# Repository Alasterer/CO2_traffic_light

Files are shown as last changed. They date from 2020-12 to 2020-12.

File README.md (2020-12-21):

# CO2 Traffic Light
DIY CO2 sensor with traffic light and 7-segment display for air quality indication.

<p float="left">
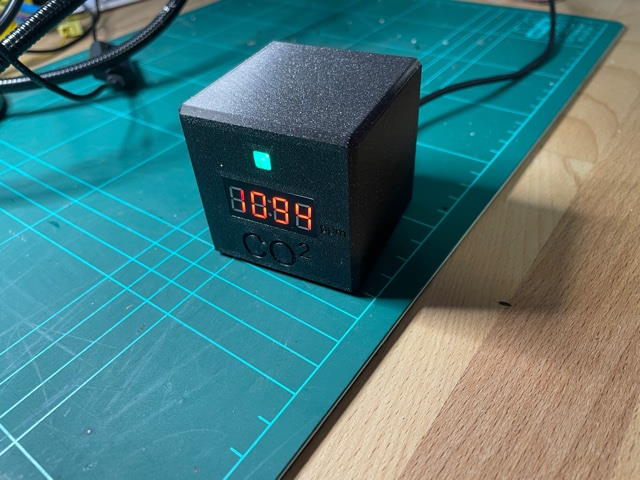
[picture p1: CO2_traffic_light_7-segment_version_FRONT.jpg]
 
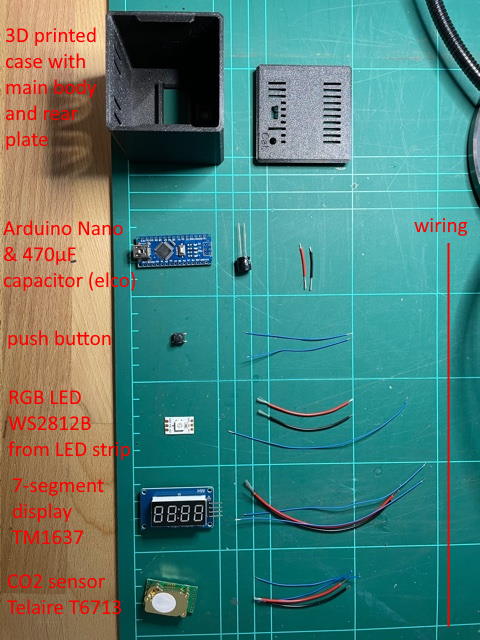
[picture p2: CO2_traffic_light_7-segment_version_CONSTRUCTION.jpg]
 
</p>
<p float="left">
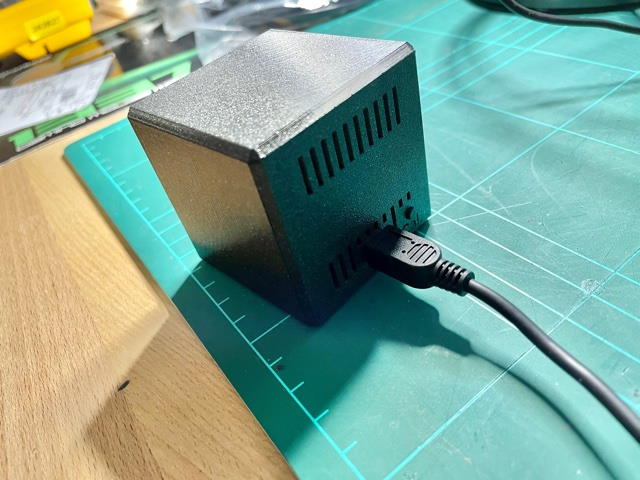
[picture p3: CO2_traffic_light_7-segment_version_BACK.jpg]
 
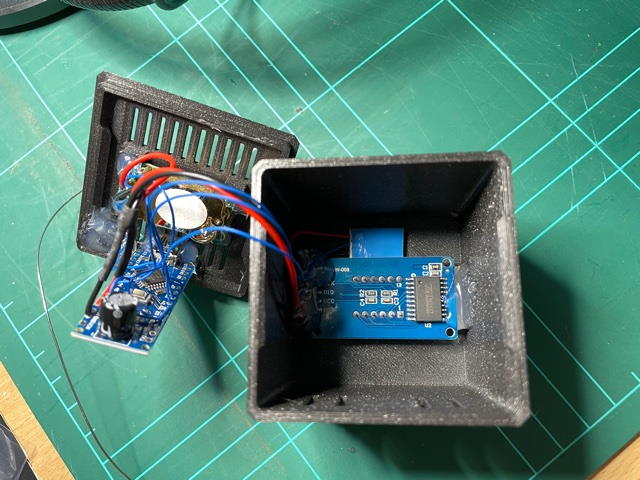
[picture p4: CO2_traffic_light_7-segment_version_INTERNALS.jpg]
 
</p>

## Purpose

I wanted to be able to measure the CO2 content of the air inside my appartment and the office.
The targets are:
  * To preventing the spread of the corona virus (adhering to the guidelines) I need to be able to know when the room needs fresh air (especially useful when colleagues are in the same office space)
  * Prevent high CO2 content in the room since this impacts directly my productivity and ability to think straight (especially useful during work hours)

## 7-segment version

DIY CO2 sensor with the following features:
  * CO2 sensor ([Telaire T6713](https://www.14core.com/wiring-the-telaire-t6713-t67xx-a-carbon-dioxide-co2-sensor/amp), [PDF datasheet](https://www.mouser.com/pdfDocs/AAS-916-142A-Telaire-T67xx-CO2-Sensor-022719-web.pdf)) for measuring real air CO2 content (it is not a equivalent CO2 sensor)
  * 7-segment display ([TM1637](https://www.makerguides.com/tm1637-arduino-tutorial), 4 digits, [PDF datasheet controller](https://www.mcielectronics.cl/website_MCI/static/documents/Datasheet_TM1637.pdf)) to show current CO2 measurement in ppm (unit for CO2)
  * RGB LED ([WS2812B](https://www.mschoeffler.de/2017/08/24/how-to-control-an-led-pixel-strip-ws2812b-with-an-arduino-and-the-fastled-library), [PDF datasheet](https://cdn-shop.adafruit.com/datasheets/WS2812B.pdf)) as traffic light to show the current air quality assessment. The following values are averaged over multiple online sources regarding CO2 threshold levels and were experimentally tested to be good values (air feels "stuffy" vs. air feels "clean"):
    * 0 to 1600 ppm: green light, air quality is good
    * 1600 to 2200 ppm: yellow light, air quality could be better, please air the room
    * above 2200 ppm (max for sensor is 5000 ppm): red light, air quality is bad, concentration problems could occur above this threshold, air room as soon as possible
  * Push button with 2 functions:
    * short press (< 1 s): change brightness of RGB LED and 7-segment display. Useful to adjust brightness for use at night or with direct sunlight.
    * long press (>= 10 s): start and perform calibration of CO2 sensor (Telaire T6713). Calibration takes about 7 to 8 minutes to complete.
  * Central microcontroller module (Arduino Nano, [Pinout](https://i.pinimg.com/originals/c4/87/21/c487213e9081fb0050878a02304e5693.png), [PDF datasheet microcontroller ATMega328P](http://ww1.microchip.com/downloads/en/DeviceDoc/Atmel-7810-Automotive-Microcontrollers-ATmega328P_Datasheet.pdf)) outputs new CO2 ppm value as simulated serial port with 115200 baud. You can use general tools for accessing the serial data or use my Python scripts:
    * [serial_logger_v5_working.py](https://github.com/Alasterer/CO2_traffic_light_7_segment/blob/main/serial_logger_v5_working.py): Logging serial data
      * Records to .csv files
      * Names .csv files after current date and time
      * Creates counter at end of file name if file with same name is present
      * Starts new .csv file after midnight to keep data steam manageable
      * Creates time stamps in front of measurement data and records this to .csv files as the first element in each line
    * [plot_serial_data_v2_working.py](https://github.com/Alasterer/CO2_traffic_light_7_segment/blob/main/plot_serial_data_v2_working.py): Plot measurement data to live graph with .png export

### Notes
  * There is a small window in front of the RGB LED which was printed using clear PLA (noname brand material)
  * The main body and rear plate were printed using [PLA Prusament Galaxy Black](https://shop.prusa3d.com/de/prusament/711-prusament-pla-prusa-galaxy-black-1kg.html) which prints very nicely. Layer height was 0.2mm using a Prusa i3 MK3S with standard prusament settings set in Prusa Slicer.

### Block diagram
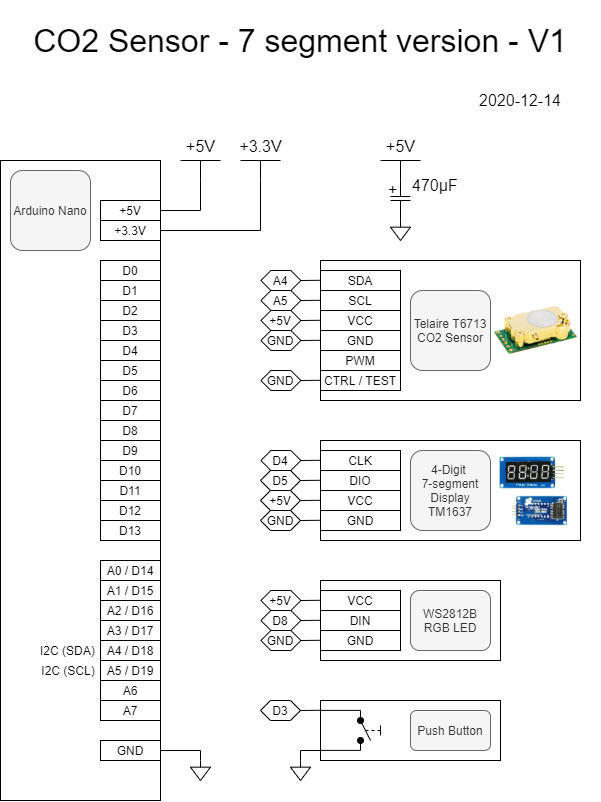
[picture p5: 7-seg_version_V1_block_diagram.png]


---

## LCD display version

It is planned to complete a version with LCD display (Nokia 5110) that has several more features:
  * [Nokia 5110 LCD display](https://learn.sparkfun.com/tutorials/graphic-lcd-hookup-guide) (has background LED), [PDF datasheet controller](https://www.sparkfun.com/datasheets/LCD/Monochrome/Nokia5110.pdf)
  * Push buttons, 3x, SMD: For navigating on screen menu on LCD screen
  * Night light LED (warm white, 5V, PWM dimming) for soft room illumination at night
  * Photoresistor ([GL5516](http://static.cactus.io/img/sensors/light/ldr/ldr-circuit.jpg) with 5 to 10 kOhm at 10 Lux) for detection ambient light levels (can be used to dim RGB LED, Night light LED and/or display backlight)
  * Connector for [BMP180 sensor module](http://www.esp8266learning.com/wemos-mini-bmp180-shield.php), [PDF datasheet](https://cdn-shop.adafruit.com/datasheets/BST-BMP180-DS000-09.pdf): Can measure temperature and ambient barometric pressure. Values will be display on LCD as well
  * Connector for [NRF24L01 communication module](https://lastminuteengineers.com/nrf24l01-arduino-wireless-communication/), [PDF datasheet](https://www.sparkfun.com/datasheets/Components/SMD/nRF24L01Pluss_Preliminary_Product_Specification_v1_0.pdf):
    * Use case 1: Communicate with separate Arduino that activates fan to vent room when CO2 levels are too high
    * Use case 2: Communicate with Raspberry Pi for recording measurement values

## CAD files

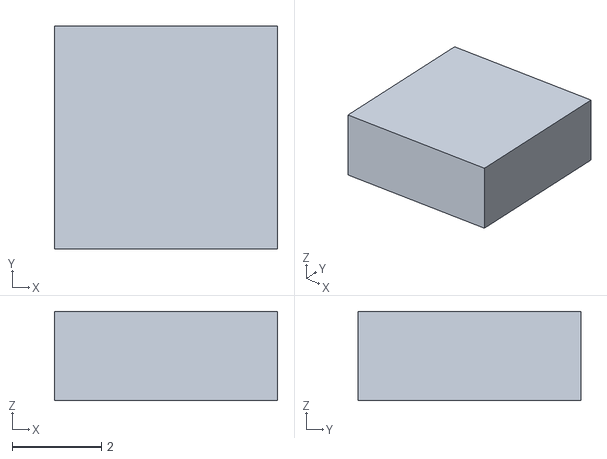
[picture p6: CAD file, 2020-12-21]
CO2 Ampel Version 7-Segment Tischgeraet v31 - Clear window.stl
5.00 x 5.00 x 2.00

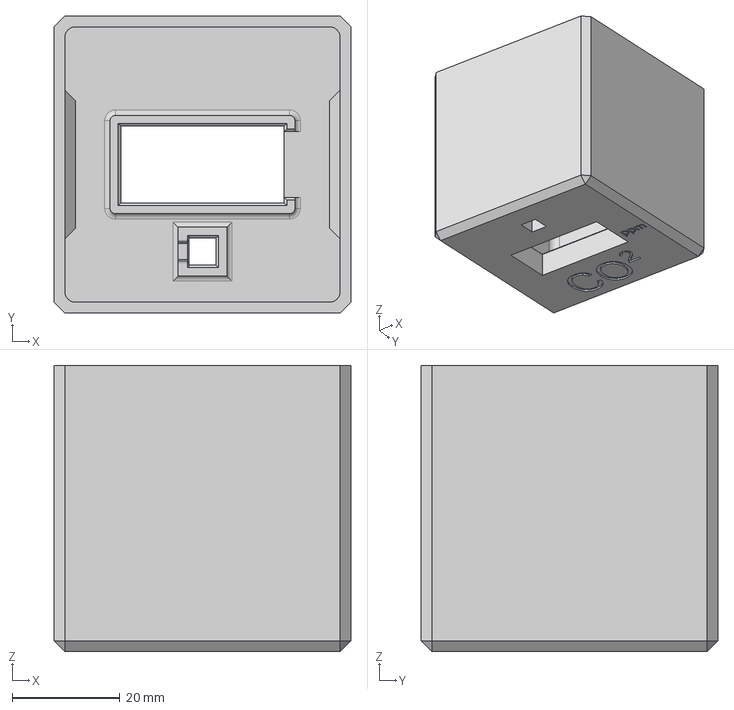
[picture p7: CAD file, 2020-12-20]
CO2 Ampel Version 7-Segment Tischgeraet v31.step
55.0 x 55.0 x 53.0 mm

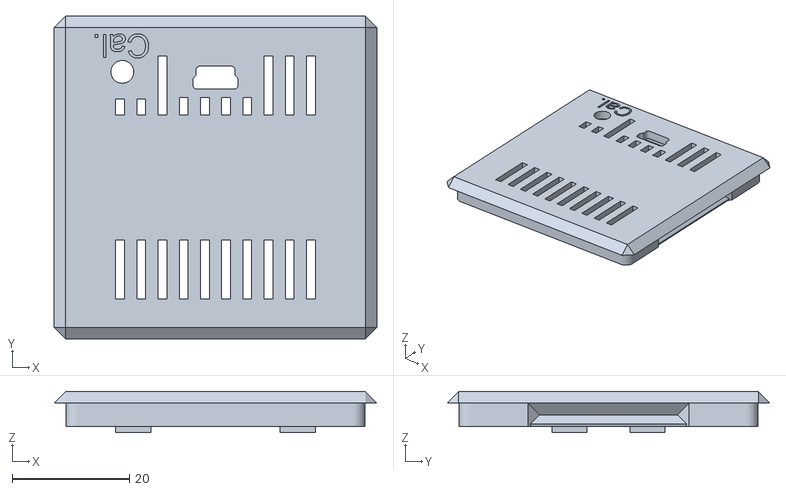
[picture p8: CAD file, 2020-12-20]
CO2 Ampel Version 7-Segment Tischgeraet v31 - Deckel.stl
55.0 x 55.0 x 7.00

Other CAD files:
CO2 Ampel Version 7-Segment Tischgeraet v31 - Hauptkoerper.stl

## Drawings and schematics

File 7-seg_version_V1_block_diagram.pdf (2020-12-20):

+5V +3.3V

# CO2 Sensor - 7 segment version - V1

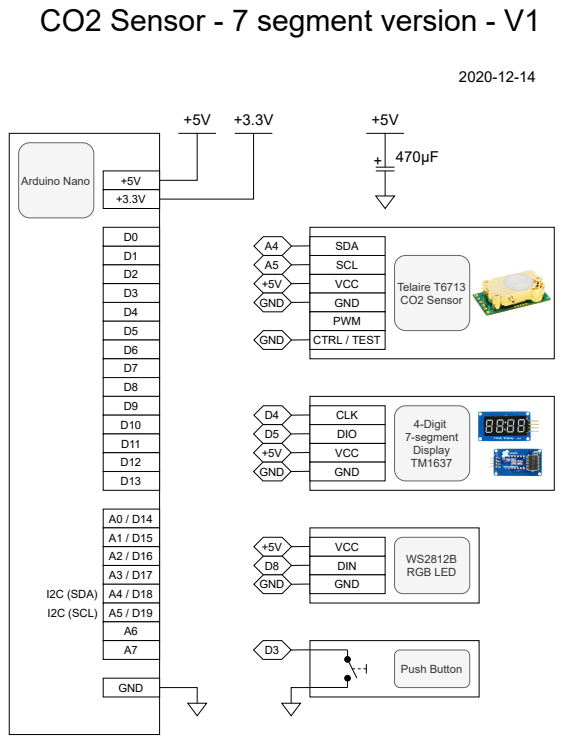
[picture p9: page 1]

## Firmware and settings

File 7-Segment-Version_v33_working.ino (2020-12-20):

#include <Arduino.h>
#include <TM1637Display.h>  // include for 7-segment display TM1637
#include <Wire.h>           // include for CO2 Sensor Telaire T67xx (i have T6713)
#include <FastLED.h>        // inclue for RGB LED WS2812B
//#include <EEPROM.h>         // for saving variables

// ----- Define Pins ----------------------------------

// 7 segment display pins
#define CLK       (byte)4
#define DIO       (byte)5

// push button pins
#define buttonpin (byte)3

// RGB LED WS2812B pins
#define RGBLEDpin (byte)8

// ----- Define parameters ----------------------------
//#define SeuilPPM1 (int)900        //1er Seuil d'alerte au CO2 (900 PPM : air bon à moyen)
#define Level_yellow (int)1600       //2nd Seuil d'alerte au CO2 (1600 PPM : air moyen à mauvais, ventillation conseillee)
#define Level_red (int)2200       //3e Seuil d'alerte au CO2 (2200 PPM : mauvais air, maux de tetes, malaise possible, ventillation indispensable)
#define T6713_Address 0x15 //T6713 i2C Address

int SensorInterval = 5500;   // Interval for reading CO2 sensor values

byte co2_offset;


unsigned long loadTime = 2000;     //temps de "chauffe" du capteur CO2
unsigned long calibrationTime = 420000;   // 7 * 60000;   // calibration take 6 min so we set 7 min to be sure that calibration is finished
int loadSpeed = 10;       //rapiditée de l'animation de chargement
int messageInterval = 4;  //fréquence des messages d'alerte si un seuil CO2 est passé (4 par défaut)
bool button_state;

uint8_t CO2[] = { 0x39, 0x5c, 0x5b, 0x00 };   // code for showing "CO2"  on 7-segment display
uint8_t CAL[] = { 0x39, 0x77, 0x38, 0x00 };   // code for showing "CAL"  on 7-segment display
uint8_t Done_Display[] = { 0x5E, 0x5c, 0x54, 0x79 };  // code for showing "DONE" on 7-segment display

// init variables and objects   
TM1637Display displayScreen(CLK, DIO);
unsigned long getDataTimer = 20000;
int CO2PPM = 0;
int messageBox = 0;

CRGB leds[1];     // Define variables for RGB LED WS2812B
byte led_state = 0;             //0=off, 1=green, 2=yellow, 3=red, 4=blue, 5=pink
byte previous_led_state = 0;    //0=off, 1=green, 2=yellow, 3=red, 4=blue, 5=pink
//byte overall_brightness;    //1=lowest , 2=normal , 3=high , 4=very high brightness
int overall_brightness = 1;    //1=lowest , 2=normal , 3=high , 4=very high brightness
float brightness = 2.0;
byte brightness_RGB_LED = 15;



// ----- Setup ---------------------------------------//

void setup()
{
  // init and set input and output pins
  pinMode(buttonpin, INPUT_PULLUP);
  pinMode(RGBLEDpin, OUTPUT);
  digitalWrite(RGBLEDpin, LOW);     // init RGB LED data channel with LOW

  // init and start serial
  Serial.begin(115200);

  // start I2C communication
  Wire.begin();  

  // init and start EEPROM library
  //EEPROM.begin(4);        // start reading EEPROM and use only first 4 bytes or EEPROM memory (4096 byte would be possible)

  // Start RGB LED
  FastLED.addLeds<WS2812B, RGBLEDpin, RGB>(leds, 1);
  clearLED();

  // initialize and set 7-seg display and RGB LED brightnesses
  //init_brightness();
  set_brightness();             // increases overall_brightness to 2 and sets the "normal" setting

  // set 7-seg display
  uint8_t clear_lcd_data[] = {0x40, 0x40, 0x40, 0x40};
  displayScreen.setSegments(clear_lcd_data);                  // writes only dashes to 7-segment display

  //readSensor();
  //loadingAnimation();                                         // Start loading animation

  // Start CO2 sensor
  turnonABCLogic();

  // print welcome message
  //Serial.println(F("Sensor stared and active!"));
}

// ----- MAIN PROGRAM ---------------------------------------//

void loop() {
  button_state = digitalRead(buttonpin);
  if ( button_state == 0 ){
    delay(500);
    button_state = digitalRead(buttonpin);
    if ( button_state == 1 ){
      previous_led_state = led_state; 
      for(int i=0; i<2; i++){
        setLED_pink();
        delay(100);
        clearLED();
        delay(100);        
      }            
      set_brightness();
    } else{
      delay(9500);
//      previous_led_state = led_state;
//      for(int i=0; i<15; i++){
//        setLED_blue();
//        delay(100);
//        clearLED();
//        delay(100);        
//      }
//      led_state = previous_led_state;
      button_state = digitalRead(buttonpin);
      if ( button_state == 0 ){
        displayScreen.setSegments(CAL);
        setLED_blue();
        //delay(7000);      
        loadTime = calibrationTime;
        loadSpeed = 420;       //rapiditée de l'animation de chargement
        calibrateSensor();
        //loadingAnimation();
        //calibrationAnimation();      
        clearLED();
        displayScreen.setSegments(Done_Display);
        getDataTimer = millis();
      }
    }
  }

  if (millis() - getDataTimer >= SensorInterval)
  {
    getDataTimer = millis();
    //CO2PPM = CO2PPM + 200;
    // getStatus_short_output();
    CO2PPM = readSensor() + co2_offset;
    // getStatus_short_output();
    if (CO2PPM > 370) {
      Serial.println(CO2PPM);
      if ( CO2PPM < Level_yellow){
        setLED_green();
      } else if ( CO2PPM >= Level_yellow && CO2PPM < Level_red ){
        setLED_yellow();
      } else {
        setLED_red();
      }
      //displayScreen.showNumberDecEx(CO2PPM, false);
      displayScreen.showNumberDec(CO2PPM);
    }
  }
}


// --------------------------------------------------------//

//void calibrationAnimation() {
//  uint8_t loadA[] = { 0x39, 0x77, 0x38, 0x01 };                //loading animation 1/6
//  uint8_t loadB[] = { 0x39, 0x77, 0x38, 0x02 };                //loading animation 2/6
//  uint8_t loadC[] = { 0x39, 0x77, 0x38, 0x04 };                //loading animation 3/6
//  uint8_t loadD[] = { 0x39, 0x77, 0x38, 0x08 };                //loading animation 4/6
//  uint8_t loadE[] = { 0x39, 0x77, 0x38, 0x10 };                //loading animation 5/6
//  uint8_t loadF[] = { 0x39, 0x77, 0x38, 0x20 };                //loading animation 6/6
//
//  int delay_per_segment = 400;
//  calibrationTime = 4800;
//  int runtime = (int)calibrationTime / (6 * delay_per_segment);
//  for (int i = 0; i <= runtime; i++) {
//    displayScreen.setSegments(loadA);
//    delay(delay_per_segment);
//    displayScreen.setSegments(loadB);
//    delay(delay_per_segment);
//    displayScreen.setSegments(loadC);
//    delay(delay_per_segment);
//    displayScreen.setSegments(loadD);
//    delay(delay_per_segment);
//    displayScreen.setSegments(loadE);
//    delay(delay_per_segment);
//    displayScreen.setSegments(loadF);
//    delay(delay_per_segment);
//  }
//  displayScreen.clear();
//}

void loadingAnimation()
{
  uint8_t loadA[] = { 0x30, 0x00, 0x00, 0x00 };                //animation de chargment 1/5
  uint8_t loadB[] = { 0x06, 0x30, 0x00, 0x00 };                //animation de chargment 2/5
  uint8_t loadC[] = { 0x00, 0x06, 0x30, 0x00 };                //animation de chargment 3/5
  uint8_t loadD[] = { 0x00, 0x00, 0x06, 0x30 };                //animation de chargment 4/5
  uint8_t loadE[] = { 0x00, 0x00, 0x00, 0x06 };                //animation de chargment 5/5

  //Affiche l'aniamtion en boucle
  for (int i = 0; i <= loadSpeed; i++) {
    displayScreen.setSegments(loadA);
    delay((loadTime / loadSpeed) / 5);
    displayScreen.setSegments(loadB);
    delay((loadTime / loadSpeed) / 5);
    displayScreen.setSegments(loadC);
    delay((loadTime / loadSpeed) / 5);
    displayScreen.setSegments(loadD);
    delay((loadTime / loadSpeed) / 5);
    displayScreen.setSegments(loadE);
    delay((loadTime / loadSpeed) / 5);
  }
  //uint8_t clear_lcd_data[] = {0x00, 0x00, 0x00, 0x00};
  uint8_t clear_lcd_data[] = {0x40, 0x40, 0x40, 0x40};
  displayScreen.setSegments(clear_lcd_data);
}

void setLED_red(){
  //leds[0] = CRGB( 255, 0, 0);  // Set RGB LED to green
  leds[0] = CRGB( 0, 255, 0);  // Set RGB LED to red
  //leds[0] = CRGB( 0, 0, 255);  // Set RGB LED to blue
  FastLED.setBrightness(brightness_RGB_LED);  // Set brightness to 5 (0...255 possible)
  FastLED.show();
  led_state = 3;
}

void setLED_yellow(){
  //leds[0] = CRGB( 255, 0, 0);  // Set RGB LED to green
  //leds[0] = CRGB( 0, 255, 0);  // Set RGB LED to red
  //leds[0] = CRGB( 0, 0, 255);  // Set RGB LED to blue
  leds[0] = CRGB( 190, 255, 0);  // Set RGB LED to yellow
  FastLED.setBrightness(brightness_RGB_LED);  // Set brightness to 5 (0...255 possible)
  FastLED.show();
  led_state = 2;
}

void setLED_green(){
  leds[0] = CRGB( 255, 0, 0);  // Set RGB LED to green
  //leds[0] = CRGB( 0, 255, 0);  // Set RGB LED to red
  //leds[0] = CRGB( 0, 0, 255);  // Set RGB LED to blue
  FastLED.setBrightness(brightness_RGB_LED);  // Set brightness to 5 (0...255 possible)
  FastLED.show();
  led_state = 1;  
}

void setLED_blue(){
  //leds[0] = CRGB( 255, 0, 0);  // Set RGB LED to green
  //leds[0] = CRGB( 0, 255, 0);  // Set RGB LED to red
  leds[0] = CRGB( 0, 0, 255);  // Set RGB LED to blue
  FastLED.setBrightness(brightness_RGB_LED);  // Set brightness to 5 (0...255 possible)
  FastLED.show(); 
  led_state = 4; 
}

void setLED_pink(){
  //leds[0] = CRGB( 255, 0, 0);  // Set RGB LED to green
  //leds[0] = CRGB( 0, 255, 0);  // Set RGB LED to red
  //leds[0] = CRGB( 0, 0, 255);  // Set RGB LED to blue
  leds[0] = CRGB( 255, 84, 167);  // Set RGB LED to blue
  FastLED.setBrightness(brightness_RGB_LED);  // Set brightness to 5 (0...255 possible)
  FastLED.show(); 
  led_state = 5; 
}

void clearLED(){
  FastLED.clear();  // clear all pixel data
  FastLED.show();
  led_state = 0;
}

// Read current sensor value of Telaire T6713
int readSensor(){
  // start I2C
  Wire.beginTransmission(T6713_Address);
  Wire.write(0x04); Wire.write(0x13); Wire.write(0x8B); Wire.write(0x00); Wire.write(0x01);
  Wire.endTransmission();
  
  // read report of current gas measurement in ppm
  delay(5);  
  Wire.requestFrom(T6713_Address, 4); //Request 4 bytes from the sensor
  int data [4];  
  data[0] = Wire.read();
  data[1] = Wire.read();
  data[2] = Wire.read();
  data[3] = Wire.read();
//  Serial.print("FUNCTION CODE: ");
//  Serial.println(data[0], HEX);
//  Serial.print("BYTE COUNT: ");
//  Serial.println(data[1], HEX);
//  Serial.print("MOST SIGNIFICANT BIT (HEX): ");
//  Serial.println(data[2],HEX);
//  Serial.print("LEAST SIGNIFICANT BIT (HEX): ");
//  Serial.println(data[3],HEX);
  int ppmValue = ((data[2] & 0x3F ) << 8) | data[3];
  return ppmValue;
}

// Calibrate sensor Telaire T6713
void calibrateSensor(){
  Serial.println(F("Calibrating sensor, please wait..."));
  
  // start I2C and request to start Single Point Calibration (I2C)
  Wire.beginTransmission(T6713_Address);  // T6713_Address = 0x15 by default
  Wire.write(0x05); Wire.write(0x03); Wire.write(0xEC); Wire.write(0xFF); Wire.write(0x00);
  Wire.endTransmission();

  // read Modbus Response (I2C) during calibration to see if calibration has finished
  int counter = 48;   // wait for 8 min to be sure that calibration has finished
  while(counter > 0){
    delay(10000);  
    getStatus_short_output();
    counter = counter - 1;
  }

  Serial.println(F("Calibration: DONE"));
}


// Turn on ABC Logic for sensor Telaire T6713 and read back result
void turnonABCLogic_with_debug_output(){
  // start I2C and request to enable ABC Logic
  turnonABCLogic();
  
  // read Modbus Response (I2C) to command "enable ABC Logic"
  Wire.requestFrom(T6713_Address, 5); //Request 5 bytes from the sensor
  int data [5]; 
  data[0] = Wire.read();
  data[1] = Wire.read();
  data[2] = Wire.read();
  data[3] = Wire.read();
  data[4] = Wire.read();
  Serial.print(F("Turning on ABC logic: FUNCTION CODE: "));
  Serial.print(data[0], HEX);
  Serial.print(F(", Register Address (MSB): "));
  Serial.print(data[1], HEX);
  Serial.print(F(", Register Address (LSB): "));
  Serial.print(data[2],HEX);
  Serial.print(F(", Register Value (MSB) Enable ABC Logic: "));
  Serial.print(data[3],HEX);
  Serial.print(F(", Register Value (LSB) LSB will always be zero: "));
  Serial.println(data[4],HEX);
}


// Turn on ABC Logic for sensor Telaire T6713
void turnonABCLogic(){
  // start I2C and request to enable ABC Logic
  Wire.beginTransmission(T6713_Address);  // T6713_Address = 0x15 by default
  Wire.write(0x05); Wire.write(0x03); Wire.write(0xEE); Wire.write(0xFF); Wire.write(0x00);
  Wire.endTransmission();
  delay(100);
}


//Get firmware version of sensor Telaire T6713
void getFirmwareVersion(){
  // start I2C and request firmware version
  Wire.beginTransmission(T6713_Address);  // T6713_Address = 0x15 by default
  Wire.write(0x04); Wire.write(0x13); Wire.write(0x89); Wire.write(0x00); Wire.write(0x01);
  Wire.endTransmission();
  delay(100);
  
  // read Modbus Response (I2C) to command "enable ABC Logic"
  int data [4];
  Wire.requestFrom(T6713_Address, 4); //Request 4 bytes from the sensor
  data[0] = Wire.read();
  data[1] = Wire.read();
  data[2] = Wire.read();
  data[3] = Wire.read();
  Serial.print(F("Firmware version is (in HEX): 0x"));
  Serial.println(data[2],HEX);
  Serial.println(data[3],HEX);
//  Serial.print(F("FUNCTION CODE (should be HEX 0x04): "));
//  Serial.println(data[0], HEX);
//  Serial.print(F("Byte Count (should be HEX 0x02): "));
//  Serial.println(data[1], HEX);
//  Serial.print(F("Status (MSB): "));
//  Serial.println(data[2],HEX);
//  Serial.print(F("Status (LSB): "));
//  Serial.println(data[3],HEX);
}

// Get current status of sensor Telaire T6713
void getStatus(){
  // start I2C and request firmware version
  Wire.beginTransmission(T6713_Address);  // T6713_Address = 0x15 by default
  Wire.write(0x04); Wire.write(0x13); Wire.write(0x8A); Wire.write(0x00); Wire.write(0x01);
  Wire.endTransmission();
  delay(100);
  
  // read Modbus Response (I2C) to command "enable ABC Logic"
  int data [4];
  Wire.requestFrom(T6713_Address, 4); //Request 4 bytes from the sensor
  data[0] = Wire.read();
  data[1] = Wire.read();
  data[2] = Wire.read();
  data[3] = Wire.read();
  Serial.println(F("RESPONSE: "));
  Serial.print(F("FUNCTION CODE (should be HEX 0x04): "));
  Serial.println(data[0], HEX);
  Serial.print(F("Byte Count (should be HEX 0x02): "));
  Serial.println(data[1], HEX);
  Serial.print(F("Status (MSB): "));
  Serial.println(data[2],HEX);
  Serial.print(F("Status (LSB): "));
  Serial.println(data[3],HEX);
}

// Get current status of sensor Telaire T6713
void getStatus_short_output(){
  // start I2C and request firmware version
  Wire.beginTransmission(T6713_Address);  // T6713_Address = 0x15 by default
  Wire.write(0x04); Wire.write(0x13); Wire.write(0x8A); Wire.write(0x00); Wire.write(0x01);
  Wire.endTransmission();
  delay(100);
  
  // read Modbus Response (I2C) to command "enable ABC Logic"
  int data [4];
  Wire.requestFrom(T6713_Address, 4); //Request 4 bytes from the sensor
  data[0] = Wire.read();
  data[1] = Wire.read();
  data[2] = Wire.read();
  data[3] = Wire.read();
  Serial.print(data[0], HEX);
  Serial.print(F(" / "));
  Serial.print(data[1], HEX);
  Serial.print(F(": "));
  Serial.print(data[2],HEX);
  Serial.println(data[3],HEX);
}

//void init_brightness(){
//  overall_brightness = EEPROM.read(1);
//}

void set_brightness(){
  overall_brightness = overall_brightness + 1;
  if (overall_brightness == 1){
    brightness = 0.1;           //out of 7.0
    brightness_RGB_LED = 1;     //out of 255
  } else if (overall_brightness == 2){
    brightness = 2.0;           //out of 7.0
    brightness_RGB_LED = 15;    //out of 255    
  } else if (overall_brightness == 3){
    brightness = 4.0;           //out of 7.0
    brightness_RGB_LED = 30;    //out of 255     
  } else if (overall_brightness == 4){
    brightness = 7.0;           //out of 7.0
    brightness_RGB_LED = 255;   //out of 255 
  } else {      // overflow case --> reduce overall_brightness to 1
    overall_brightness = 1;
    brightness = 0.1;           //out of 7.0
    brightness_RGB_LED = 1;    //out of 255
  }
  displayScreen.setBrightness(brightness);      // set brightness of 7-segment display
  displayScreen.showNumberDec(CO2PPM);          // show current measurement value
  FastLED.setBrightness(brightness_RGB_LED);    // set brightness of RGB LED
  set_led_to_previous_state();
}

void set_led_to_previous_state(){
  if (previous_led_state == 0){
    clearLED();
  } else if (previous_led_state == 1){
    setLED_green();
  } else if (previous_led_state == 2){
    setLED_yellow();
  } else if (previous_led_state == 3){
    setLED_red();
  } else if (previous_led_state == 4){
    setLED_blue();
  } else if (previous_led_state == 5){
    setLED_pink();
  } else {
    clearLED();
  }
}

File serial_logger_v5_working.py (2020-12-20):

import serial
import time
import csv
import sys
from datetime import datetime
from os import path
import platform

class RelaySerial():
    def __init__(self, comport, debug=False):
        print('Opening communication...')
        self.debug = debug
        self.ser = serial.Serial()
        self.ser.port = comport 
        self.ser.baudrate = 115200
        self.ser.bytesize = serial.EIGHTBITS 
        self.ser.parity = serial.PARITY_NONE
        self.ser.stopbits = serial.STOPBITS_ONE 
        self.ser.xonxoff = False
        self.ser.writeTimeout = 2
        try: 
            self.ser.open()
            read_response = self.ser.readline()   # read a '\n' terminated line --> NEEDED!!! Arduino flash memory can otherwise be overwriten during serial initiation (then needs to be rewritten)
            # print('read_response returned: ', read_response)            
            print('Communication established')
        except Exception:
            print("Class RelaySerial Init: Error open serial port: " + str(comport))
            sys.exit('Class RelaySerial Init: Error open serial port: ' + str(comport)) 
            
    def send(self, commandToSend):            
        if self.ser.isOpen():
            try:
                self.ser.flushInput() 
                self.ser.flushOutput()
                #print("writing to serial: ", commandToSend)
                self.ser.write((commandToSend + '\n').encode())
                # read back the command we just send
                while True:
                    readback_of_send_command = str(self.ser.readline())[3:-1]
                    # print('readback_of_send_command: ', readback_of_send_command)
                    if readback_of_send_command == 'a\\n':
                        print('relay(s) activated with: ', commandToSend)
                        break
                time.sleep(0.5)
                # print('readback_of_send_command: ', readback_of_send_command)
            except Exception:
                print('Error in function send() in class RelaySerial')
                response = None
                
    def read(self):            
        if self.ser.isOpen():
            try:
                self.ser.flushInput() 
                self.ser.flushOutput()
                readback = str(self.ser.readline().decode("utf-8"))
                readback = readback.replace('\r\n','')
                #print(readback)
                time.sleep(0.5)
            except Exception:
                print('Error in function send() in class RelaySerial')
                readback = None
        return readback
                
    def read_loop(self):            
        if self.ser.isOpen():
            try:
                self.ser.flushInput() 
                self.ser.flushOutput()
                # read back the command we just send
                while True:
                    readback = str(self.ser.readline().decode("utf-8"))
                    readback = readback.replace('\r\n','')
                    print(readback)
                    if readback == 'EOF':
                        print('EOF reached')
                        break
                    time.sleep(1)
                time.sleep(0.5)
                # print('readback_of_send_command: ', readback_of_send_command)
            except Exception:
                print('Error in function send() in class RelaySerial')
                response = None                 
                
                
    def closeCom(self):
        """Close communication"""
        print('Closing communication...')
        try:
            self.ser.close()
            if not self.ser.isOpen():
                print('Communication closed successfully')
            else:
                print('Error: Communication could not be closed')
        except:
            print('Error: Communication could not be closed')
            

            
if __name__ == "__main__":
    try:
        delimiter_symbol = ';'
        running_data_file_counter = 1
        
        if platform.system() == 'Windows':
            serial_relay = RelaySerial('COM10', debug=False)
        elif platform.system() == 'Linux':
            serial_relay = RelaySerial('/dev/ttyUSB0', debug=False)
        else:
            serial_relay = RelaySerial('/dev/ttyUSB0', debug=False)
        initial_date = datetime.utcnow().strftime('%Y-%m-%d')
        output_file = initial_date + '_logging_data_' + str(running_data_file_counter) + '.csv'
        while path.exists(output_file):
            running_data_file_counter = running_data_file_counter + 1
            output_file = initial_date + '_logging_data_' + str(running_data_file_counter) + '.csv' 
                
        while(True):
            current_date = datetime.utcnow().strftime('%Y-%m-%d')
            current_time = datetime.utcnow().strftime('%Y-%m-%d;%H:%M:%S.%f')[:-3]
            if current_date != initial_date:
                initial_date = current_date
                running_data_file_counter = 1
                output_file = initial_date + '_logging_data_' + str(running_data_file_counter) + '.csv'
                while path.exists(output_file):
                    running_data_file_counter = running_data_file_counter + 1
                    output_file = initial_date + '_logging_data_' + str(running_data_file_counter) + '.csv'                
                print('output file is:', output_file)
               
            readback = serial_relay.read()      # init all relays to: deactivated
            print(readback)
            with open(output_file, 'a', encoding='utf-8') as f:   #newline='\r\n', 
                output_string = current_time + delimiter_symbol + readback + '\n'
                f.write(output_string)
                #writer = csv.writer(f, delimiter=delimiter_symbol)
                #writer.writerows([current_time, readback])
        
    except Exception as e:
        print(('Exception in main function: '+ str(e)))
        serial_relay.closeCom()       # Close serial communication to SIB module at end of test
                     
    except: # default exception (if no exception type is given, e.g. with KeyboardInterrupt)
        serial_relay.closeCom()       # Close serial communication to SIB module at end of test










         
